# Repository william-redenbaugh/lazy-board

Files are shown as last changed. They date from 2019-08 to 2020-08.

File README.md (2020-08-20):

# Teensy Based Macro Board with RGB LEDs and a TFT LCD Display

Picture of prototype one

## Build of Materials:(Work in progress) 
- Teensy 4.0
- SSD1351 128x128 1.5in OLED display
- WS2813 RGB LEDs
- Keycaps TBD
- Keyswitches TBD
- PCB TBD

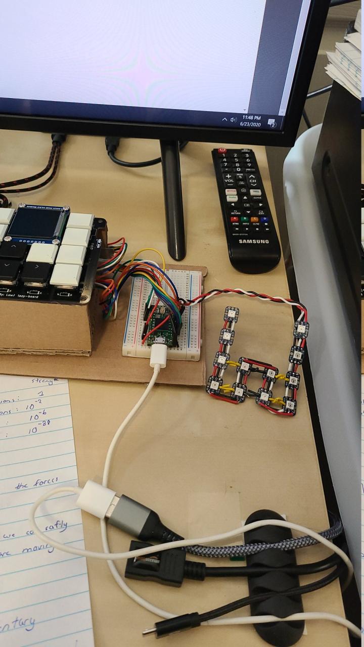
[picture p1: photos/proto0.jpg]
Picture of prototype zero


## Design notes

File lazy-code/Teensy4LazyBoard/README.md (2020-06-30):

# Teensy 4 Lazy Code
The firmware level code that will run on the lazy board. Will support RGB LED matrix, and a SPI based LCD. 

## Features: 
##### SPI DMA Based LCD Display control for pushing up gifs and images. 
##### PWM DMA Based LED Matrix for controlling the RGB LED Animations
##### Utilizes ChibiOS for multithreading purposes. 
##### Macro Configuration support through a header file
##### Interfaces with desktop app

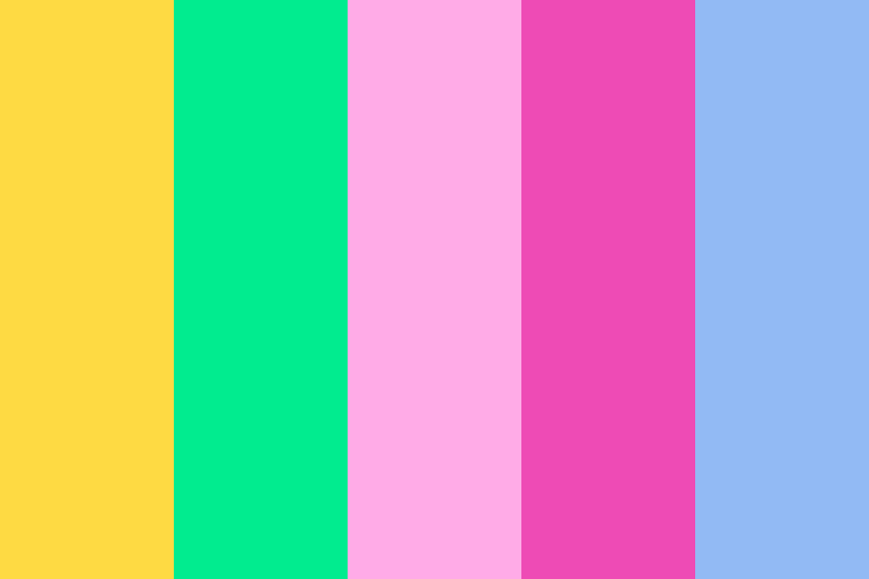
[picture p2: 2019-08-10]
Housing files/Housing working/easy_mode/pallette1.png

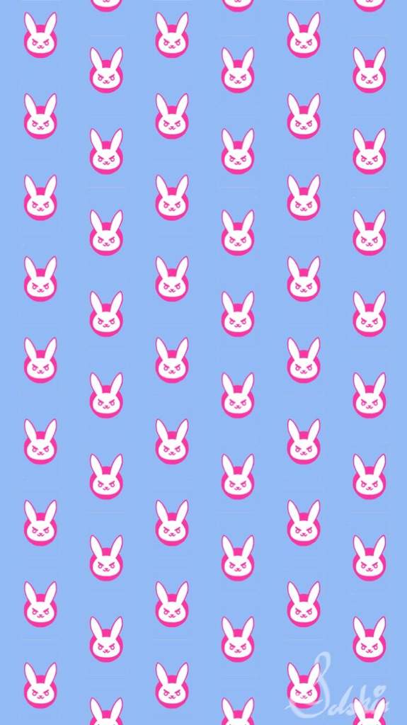
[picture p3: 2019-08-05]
Housing files/Housing working/easy_mode/1854acad1ce5d433ceb1f47706ed17edfe769c83_hq.jpg

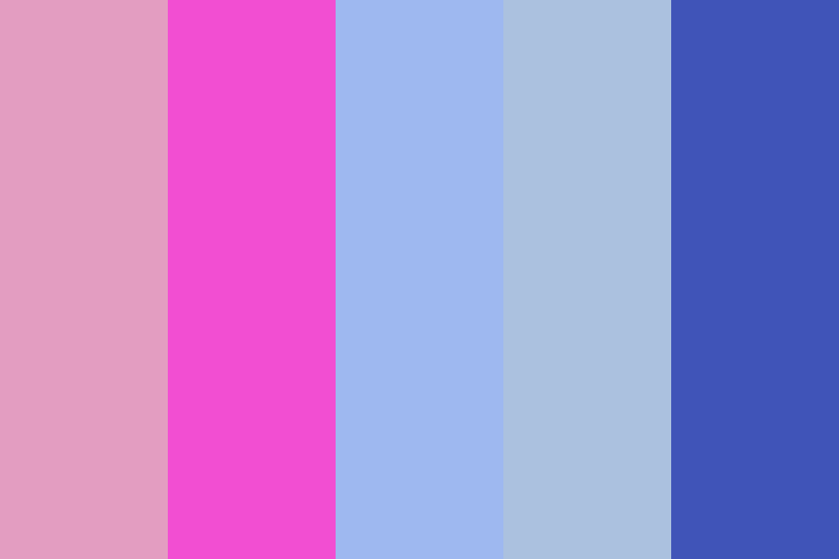
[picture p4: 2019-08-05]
Housing files/Housing working/easy_mode/pallette2.png

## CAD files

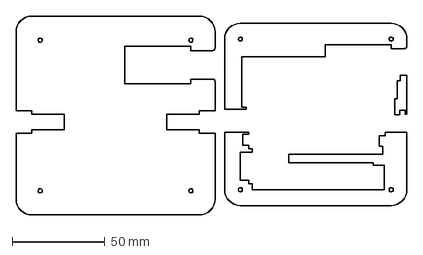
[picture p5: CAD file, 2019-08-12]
Housing files/Housing working/easy_mode/Pink/PinkLayer.dxf
210.8 x 107.3 mm

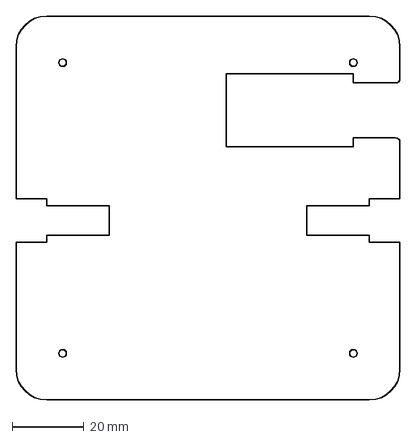
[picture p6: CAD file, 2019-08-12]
Housing files/Housing working/Layer 5/Layer5.dxf
107.3 x 107.3 mm

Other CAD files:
base.dxf
Housing files/Housing untested/DWG files(Solidworks export)/Layer3.DWG
Housing files/Housing untested/DXF(2000) files/Layer2.dxf
Housing files/Housing untested/Layer 1/Layer1.dxf
Housing files/Housing untested/Layer 2/Layer2.dxf
Housing files/Housing untested/Layer 3/Layer3.dxf
Housing files/Housing untested/Layer 4/Layer4v2.dxf
Housing files/Housing untested/Layer 5/Layer5.dxf
Housing files/Housing working/dxf 2000/Layer3.dxf
Housing files/Housing working/easy_mode/Lav/LavLayer.dxf
Housing files/Housing working/Layer 1 (bottom_cutout)/Layer1(cut_out).dxf
Housing files/Housing working/Layer 1/Layer1.dxf
Housing files/Housing working/Layer 2/Layer2.dxf
Housing files/Housing working/Layer 3/Layer3.dxf
Housing files/Housing working/Layer 4/Layer4v2.dxf
housing/Layer 4/Layer4.dxf
Housing files/Housing untested/DWG files(Solidworks export)/Layer1.DWG
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

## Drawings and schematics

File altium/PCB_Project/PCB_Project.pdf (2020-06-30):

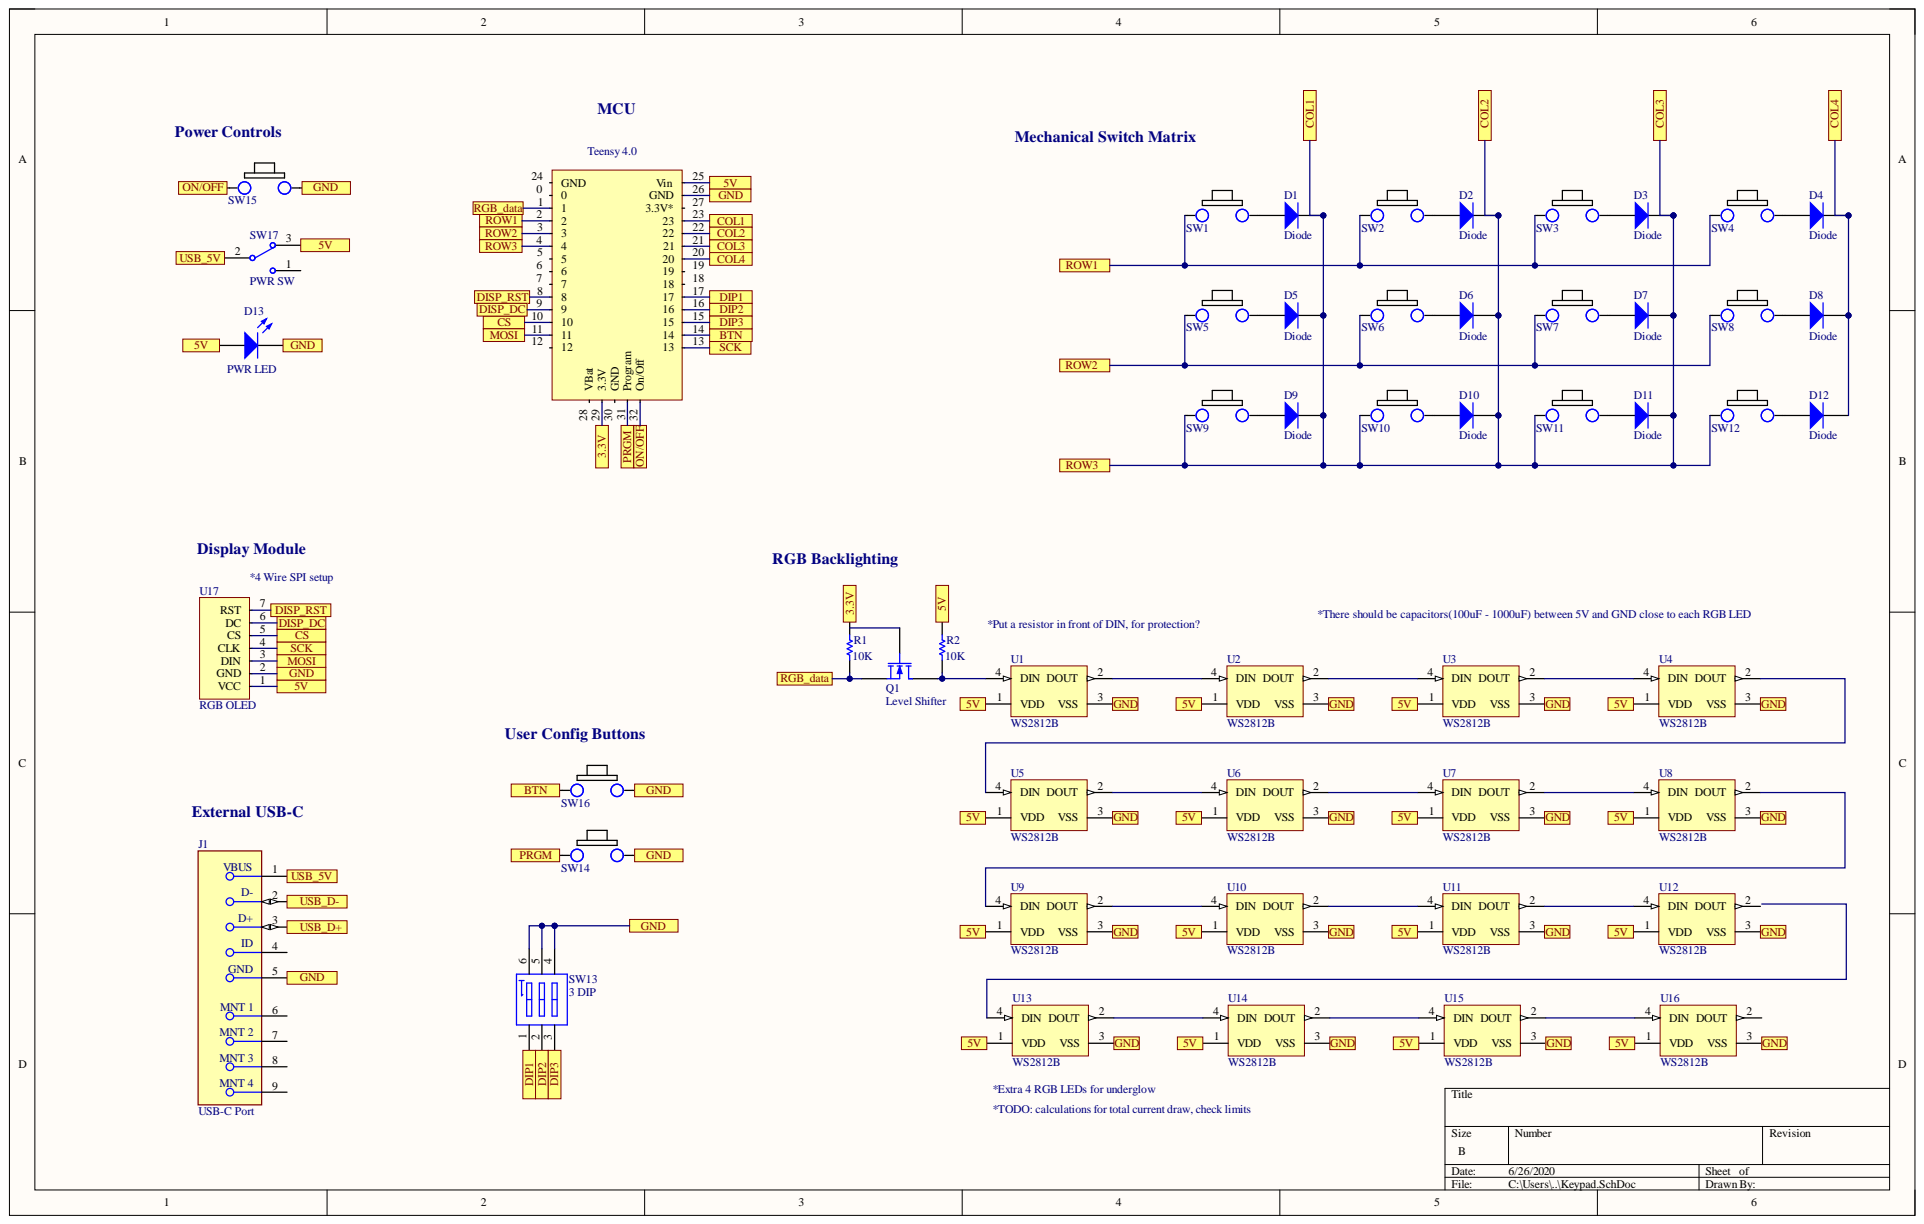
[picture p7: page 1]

RGB_data | 2 2
ROW1 | | COL1
ROW2 | | COL2

DISP_DC | 9 9 | DIP2

*Extra 4 RGB LEDs for underglow
*TODO: calculations for total current draw, check limits

Size B | Number | Revision

Date: 6/26/2020 | Sheet of
File: C:\Users\..\Keypad.SchDoc | DrawnBy:

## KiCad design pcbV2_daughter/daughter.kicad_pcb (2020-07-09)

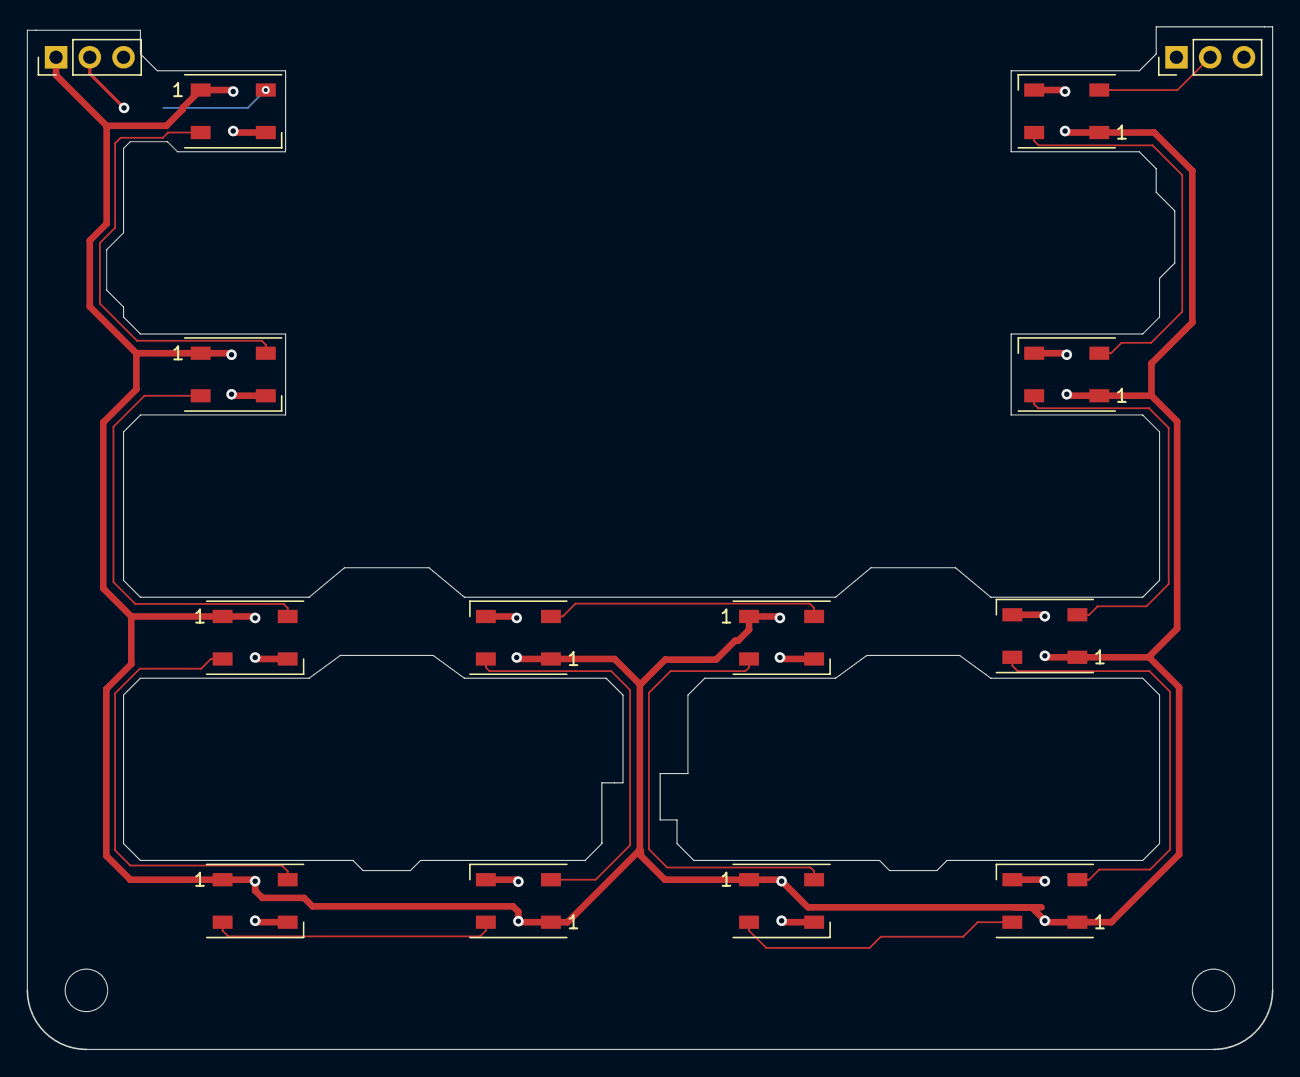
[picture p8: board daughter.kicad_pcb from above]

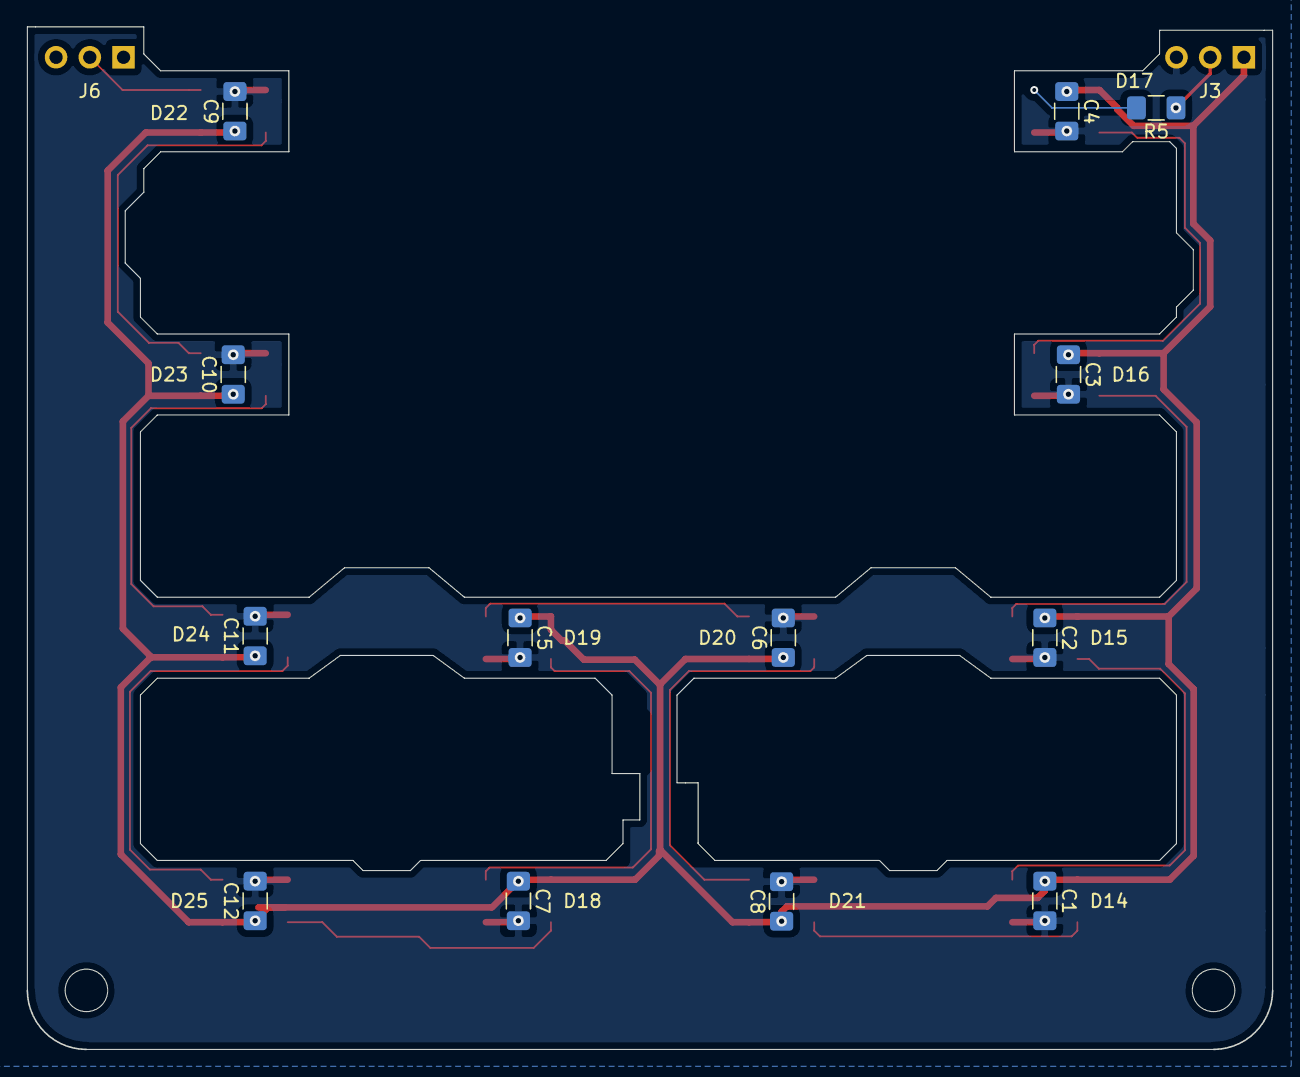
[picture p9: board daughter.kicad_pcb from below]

Board: 2 copper layers, 93.7 x 77.0 mm, 27 parts (13 on the bottom side), 16 nets.

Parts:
C1, C2, C3, C4, C5, C6, C7, C8, C9, C10, C11, C12: 1000uF; C_1206_3216Metric_Pad1.42x1.75mm_HandSolder
D14, D15, D16, D17, D18, D19, D20, D21, D22, D23, D24, D25: WS2812B; LED_WS2812B_PLCC4_5.0x5.0mm_P3.2mm
J3, J6: Conn_01x03_Male; PinHeader_1x03_P2.54mm_Vertical
R5: R_DIN; R_1206_3216Metric_Pad1.42x1.75mm_HandSolder

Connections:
+5V: C1.1, C2.1, C3.1, C4.1, C5.1, C6.1, C7.1, C8.1, C9.1, C10.1, C11.1, C12.1, D14.1, D15.1, D16.1, D17.1, D18.1, D19.1, D20.1, D21.1, D22.1, D23.1, D24.1, D25.1, J3.1
GND: C1.2, C2.2, C3.2, C4.2, C5.2, C6.2, C7.2, C8.2, C9.2, C10.2, C11.2, C12.2, D14.3, D15.3, D16.3, D17.3, D18.3, D19.3, D20.3, D21.3, D22.3, D23.3, D24.3, D25.3, J3.3
unnamed: D14.2, D21.4
unnamed: D14.4, D15.2
unnamed: D15.4, D16.2
unnamed: D16.4, D17.2
unnamed: D17.4, R5.1
unnamed: D18.2, D25.4
unnamed: D18.4, D19.2
unnamed: D19.4, D20.2
unnamed: D20.4, D21.2
unnamed: D22.4, D23.2
unnamed: D23.4, D24.2
unnamed: D24.4, D25.2
RGB_DIN: J3.2, R5.2
RGB_DOUT: D22.2, J6.2

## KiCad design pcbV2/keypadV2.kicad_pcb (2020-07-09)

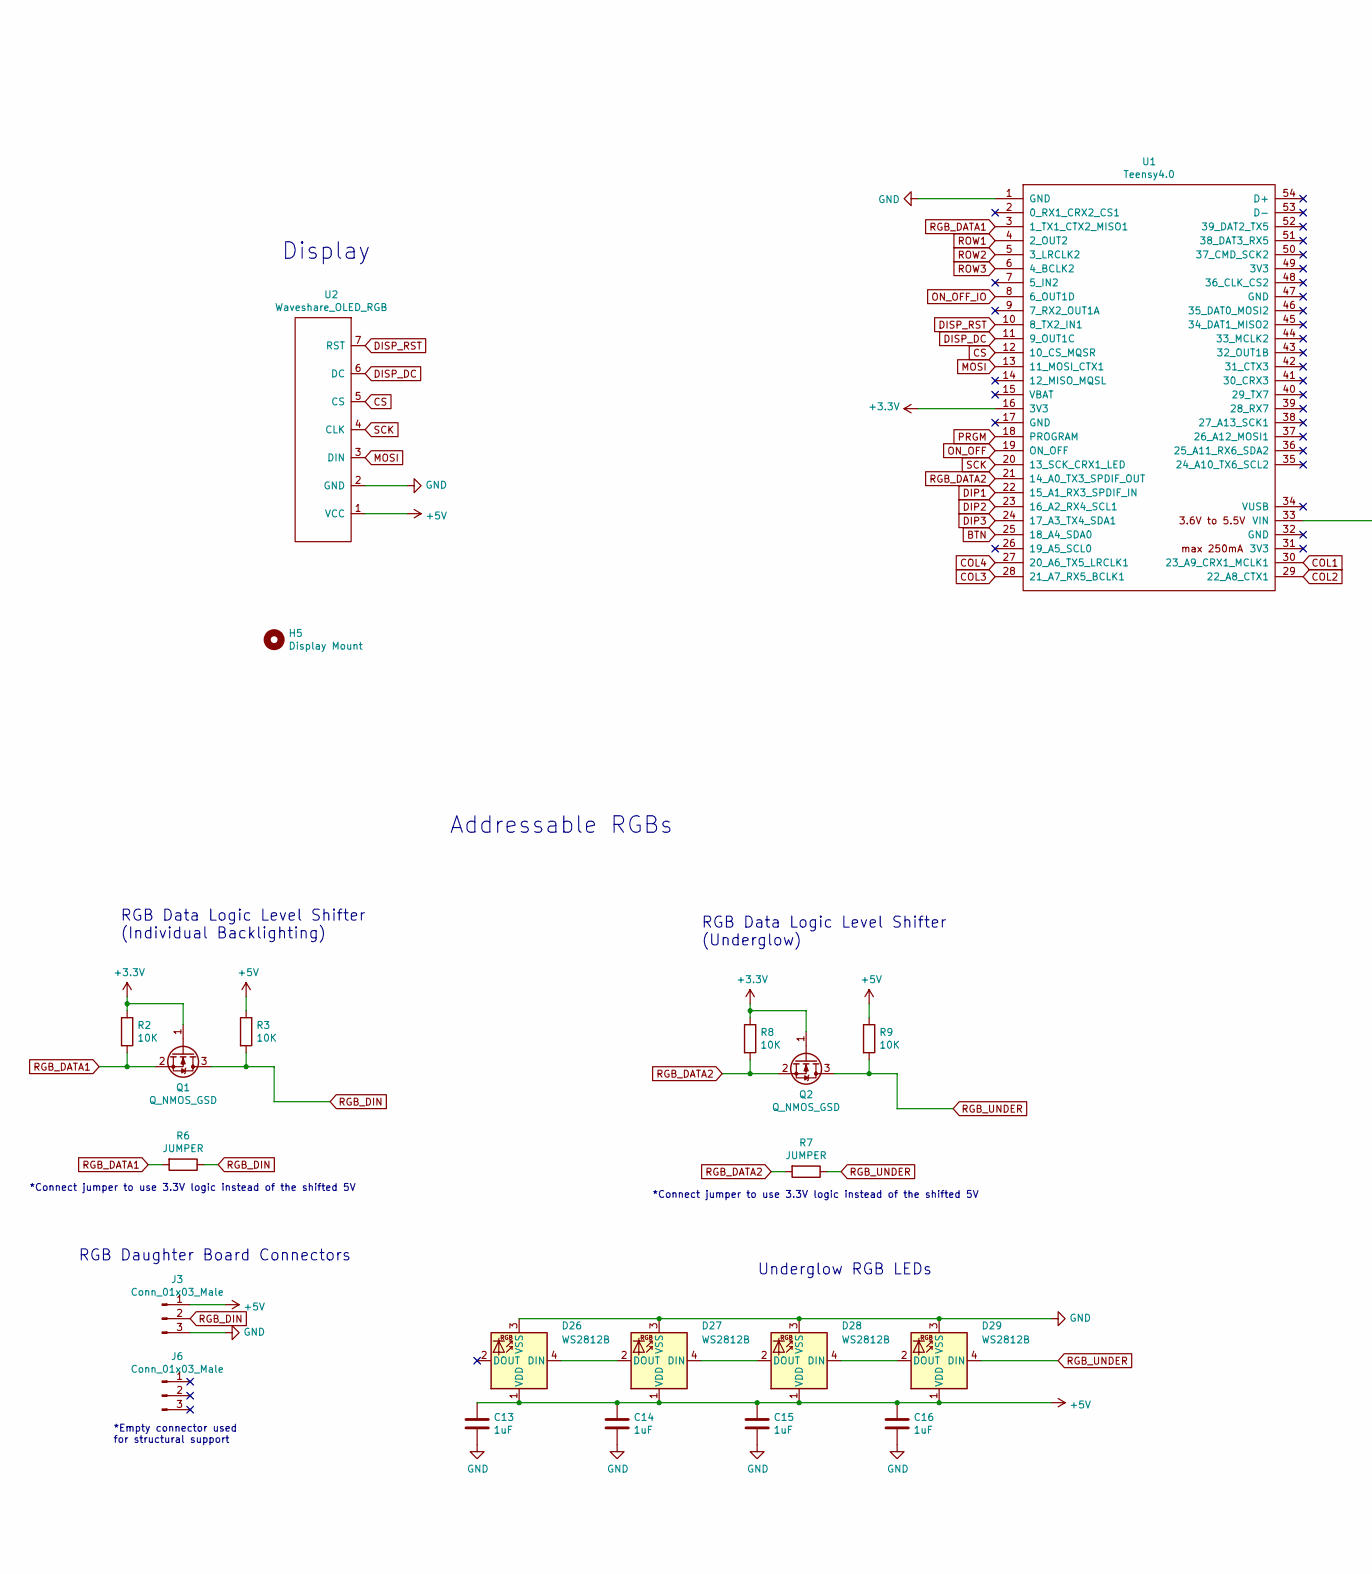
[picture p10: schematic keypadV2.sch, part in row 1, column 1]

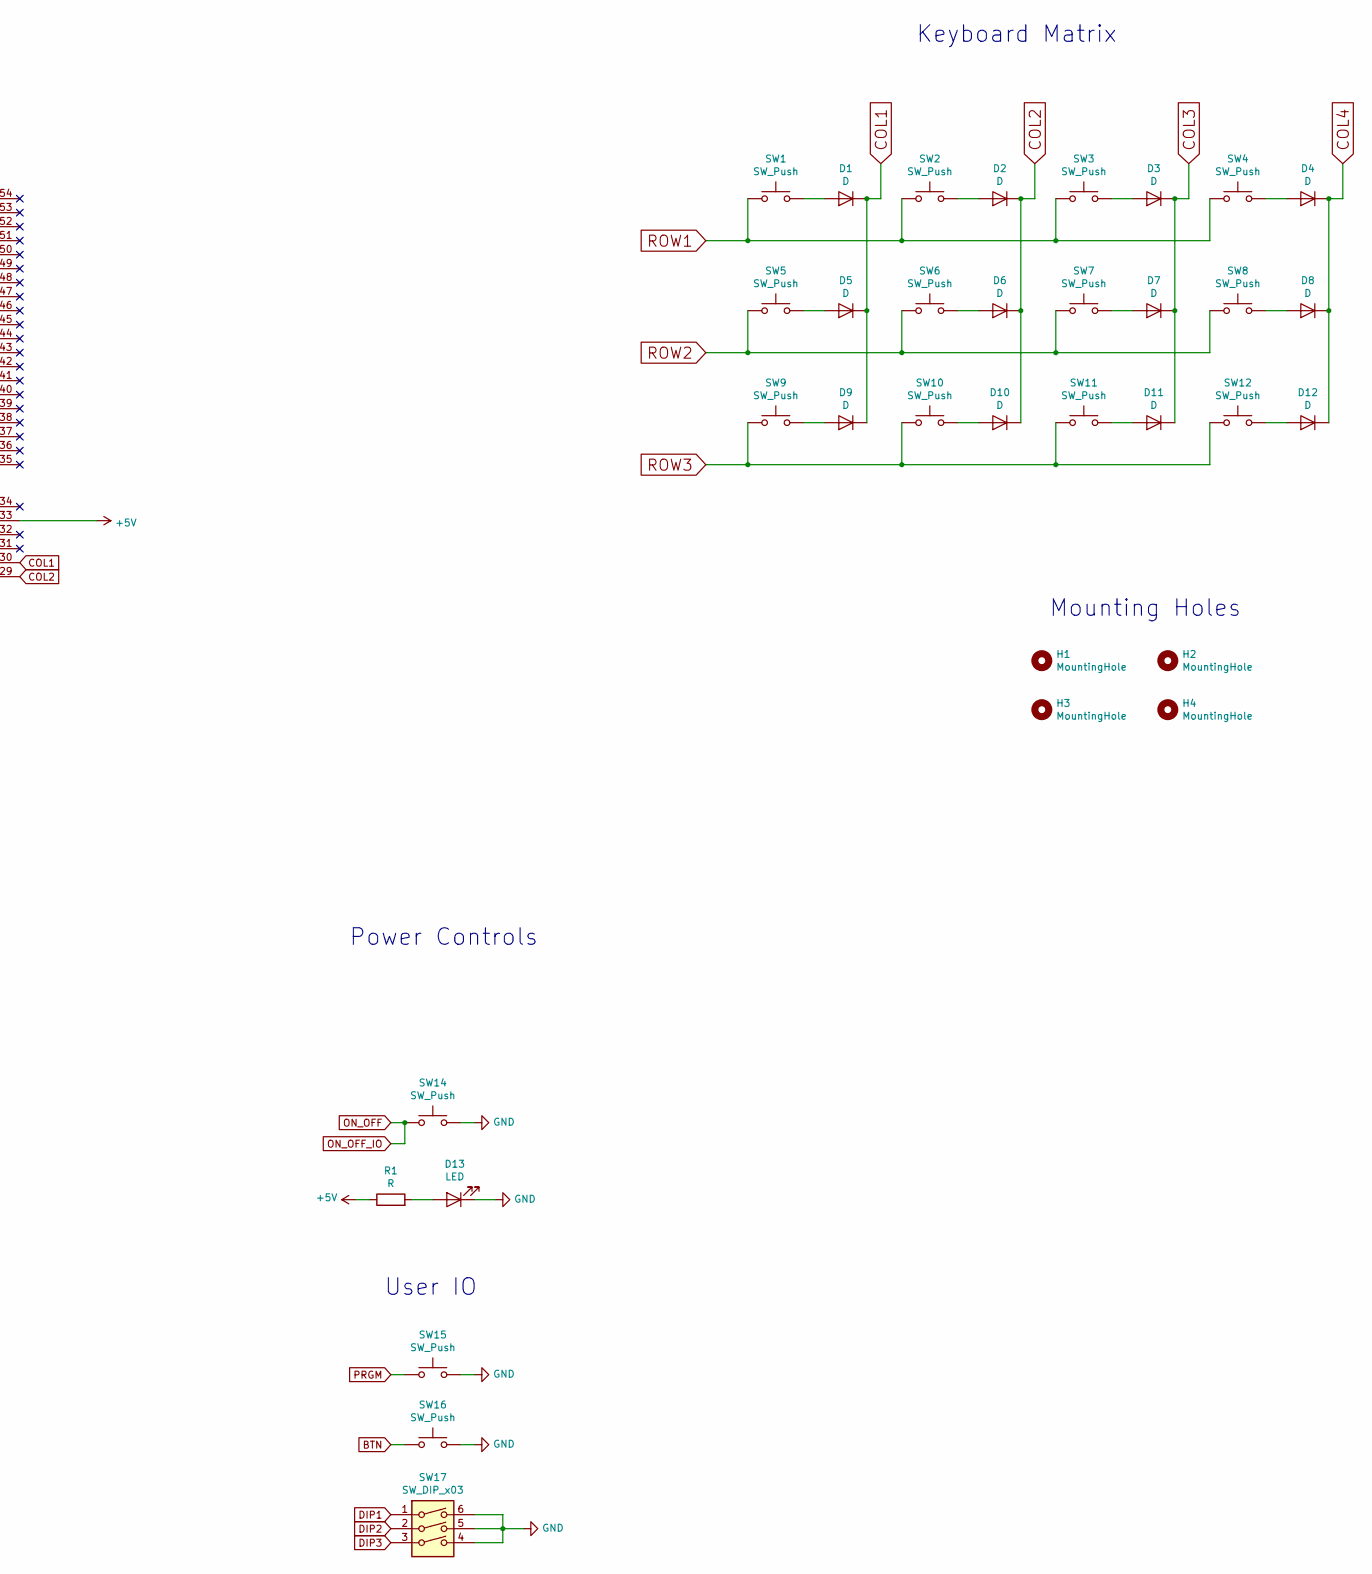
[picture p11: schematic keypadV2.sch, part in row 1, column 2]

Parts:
C13, C14, C15, C16: 1uF; C_1206_3216Metric_Pad1.42x1.75mm_HandSolder
D1, D2, D3, D4, D5, D6, D7, D8, D9, D10, D11, D12: D; D_SOD-323_HandSoldering
D13: LED; LED_1206_3216Metric_Pad1.42x1.75mm_HandSolder
D26, D27, D28, D29: WS2812B; LED_WS2812B_PLCC4_5.0x5.0mm_P3.2mm
H1, H2, H3, H4: MountingHole; MountingHole_3.2mm_M3
H5: Display Mount; Waveshare_LCD_mount V2
J3: Conn_01x03_Male; PinHeader_1x03_P2.54mm_Vertical
J6: Conn_01x03_Male; PinSocket_1x03_P2.54mm_Vertical
Q1, Q2: Q_NMOS_GSD; SOT-23
R1: R; R_1206_3216Metric_Pad1.42x1.75mm_HandSolder
R2, R3, R8, R9: 10K; R_1206_3216Metric_Pad1.42x1.75mm_HandSolder
R6, R7: JUMPER; R_1206_3216Metric_Pad1.42x1.75mm_HandSolder
SW1, SW2, SW3, SW4, SW5, SW6, SW7, SW8, SW9, SW10, SW11, SW12: SW_Push; Kailh_socket_MX
SW14, SW15, SW16: SW_Push; BTN_B3S-1000P
SW17: SW_DIP_x03; DIP3_219-3MSTR
U1: Teensy4.0; Teensy40_REDUCED_PINS
U2: Waveshare_OLED_RGB; PinHeader_1x07_P2.54mm_Vertical

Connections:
+3V3: Q1.1 (G), Q2.1 (G), R2.1, R8.1, U1.16 (3V3)
+5V: C13.1, C14.1, C15.1, C16.1, D26.1 (VDD), D27.1 (VDD), D28.1 (VDD), D29.1 (VDD), J3.1, R1.1, R3.1, R9.1, U1.33 (VIN), U2.1 (VCC)
BTN: SW16.1, U1.25 (18_A4_SDA0)
COL1: D1.1 (K), D5.1 (K), D9.1 (K), U1.30 (23_A9_CRX1_MCLK1)
COL2: D2.1 (K), D6.1 (K), D10.1 (K), U1.29 (22_A8_CTX1)
COL3: D3.1 (K), D7.1 (K), D11.1 (K), U1.28 (21_A7_RX5_BCLK1)
COL4: D4.1 (K), D8.1 (K), D12.1 (K), U1.27 (20_A6_TX5_LRCLK1)
CS: U1.12 (10_CS_MQSR), U2.5 (CS)
DIP1: SW17.1, U1.22 (15_A1_RX3_SPDIF_IN)
DIP2: SW17.2, U1.23 (16_A2_RX4_SCL1)
DIP3: SW17.3, U1.24 (17_A3_TX4_SDA1)
DISP_DC: U1.11 (9_OUT1C), U2.6 (DC)
DISP_RST: U1.10 (8_TX2_IN1), U2.7 (RST)
GND: C13.2, C14.2, C15.2, C16.2, D13.1 (K), D26.3 (VSS), D27.3 (VSS), D28.3 (VSS), D29.3 (VSS), J3.3, SW14.2, SW15.2, SW16.2, SW17.4, SW17.5, SW17.6, U1.1 (GND), U2.2 (GND)
MOSI: U1.13 (11_MOSI_CTX1), U2.3 (DIN)
unnamed: D1.2 (A), SW1.2
unnamed: D2.2 (A), SW2.2
unnamed: D3.2 (A), SW3.2
unnamed: D4.2 (A), SW4.2
unnamed: D5.2 (A), SW5.2
unnamed: D6.2 (A), SW6.2
unnamed: D7.2 (A), SW7.2
unnamed: D8.2 (A), SW8.2
unnamed: D9.2 (A), SW9.2
unnamed: D10.2 (A), SW10.2
unnamed: D11.2 (A), SW11.2
unnamed: D12.2 (A), SW12.2
unnamed: D13.2 (A), R1.2
unnamed: D26.4 (DIN), D27.2 (DOUT)
unnamed: D27.4 (DIN), D28.2 (DOUT)
unnamed: D28.4 (DIN), D29.2 (DOUT)
ON_OFF: SW14.1, U1.8 (6_OUT1D), U1.19 (ON_OFF)
PRGM: SW15.1, U1.18 (PROGRAM)
RGB_DATA1: Q1.2 (S), R2.2, R6.2, U1.3 (1_TX1_CTX2_MISO1)
RGB_DATA2: Q2.2 (S), R7.2, R8.2, U1.21 (14_A0_TX3_SPDIF_OUT)
RGB_DIN: J3.2, Q1.3 (D), R3.2, R6.1
RGB_UNDER: D29.4 (DIN), Q2.3 (D), R7.1, R9.2
ROW1: SW1.1, SW2.1, SW3.1, SW4.1, U1.4 (2_OUT2)
ROW2: SW5.1, SW6.1, SW7.1, SW8.1, U1.5 (3_LRCLK2)
ROW3: SW9.1, SW10.1, SW11.1, SW12.1, U1.6 (4_BCLK2)
SCK: U1.20 (13_SCK_CRX1_LED), U2.4 (CLK)

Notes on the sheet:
User IO
Power Controls
Display
Addressable RGBs
RGB Data Logic Level Shifter (Individual Backlighting)
*Connect jumper to use 3.3V logic instead of the shifted 5V
RGB Daughter Board Connectors
Keyboard Matrix
Underglow RGB LEDs
RGB Data Logic Level Shifter (Underglow)
*Empty connector used for structural support
Mounting Holes

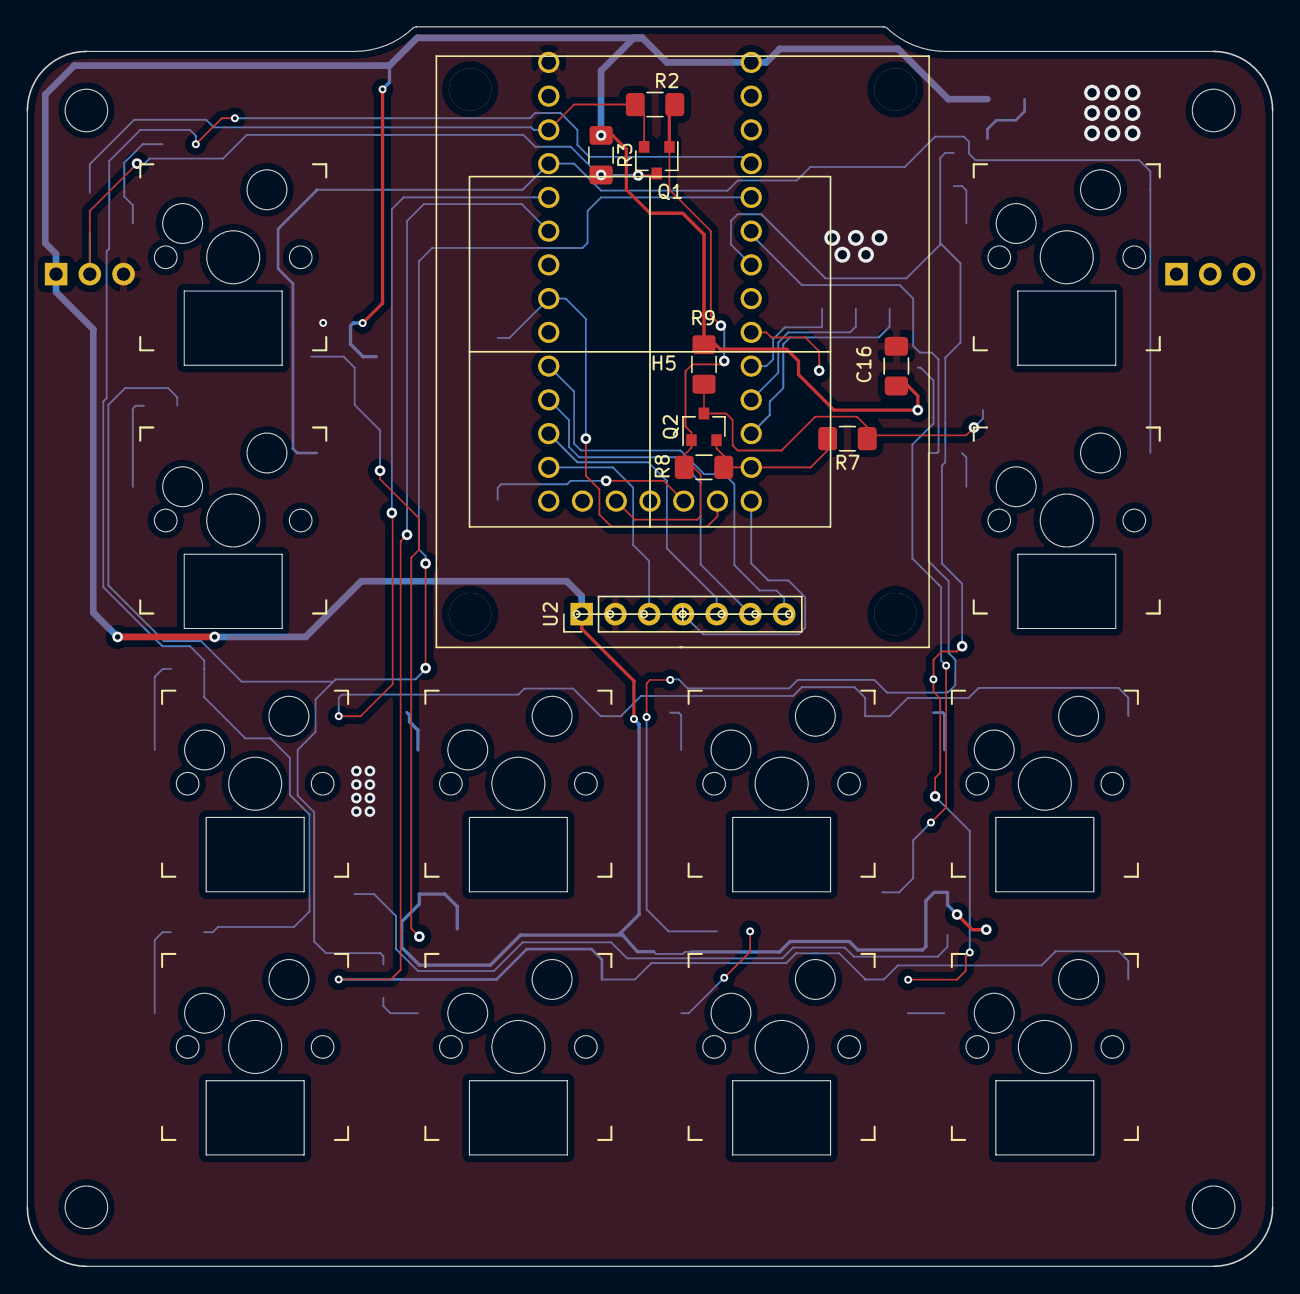
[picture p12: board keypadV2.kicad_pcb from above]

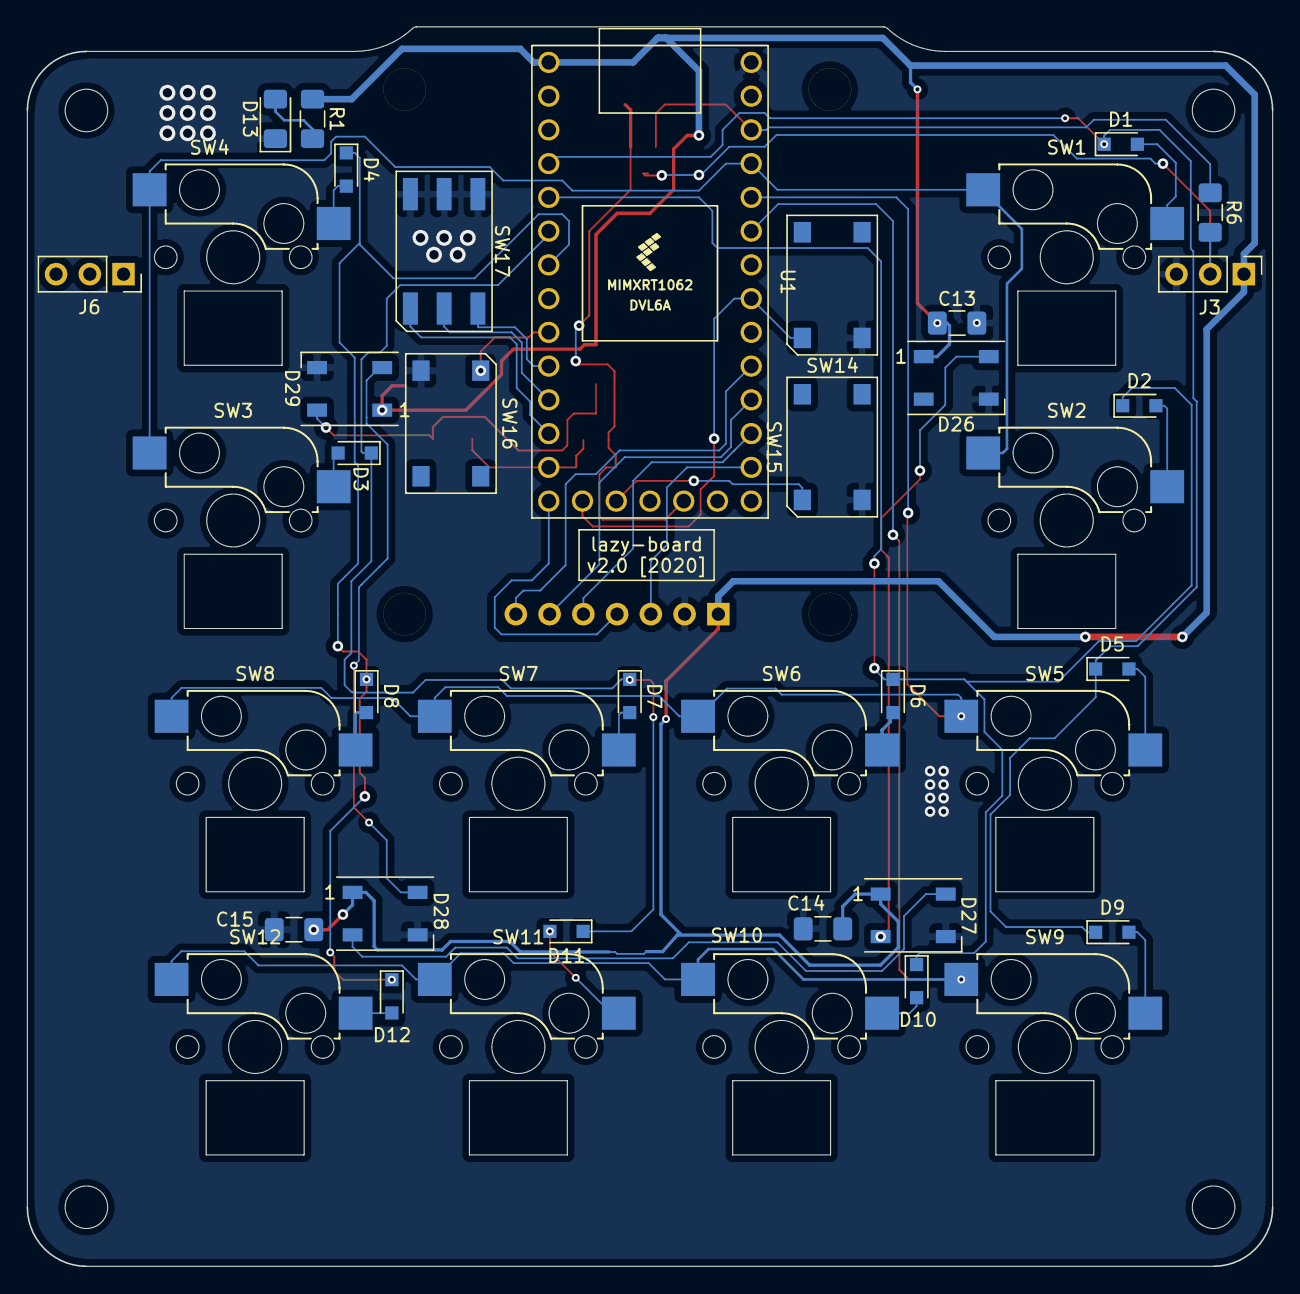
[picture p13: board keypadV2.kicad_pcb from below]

Board: 2 copper layers, 93.7 x 93.3 mm, 55 parts (28 on the bottom side), 41 nets.

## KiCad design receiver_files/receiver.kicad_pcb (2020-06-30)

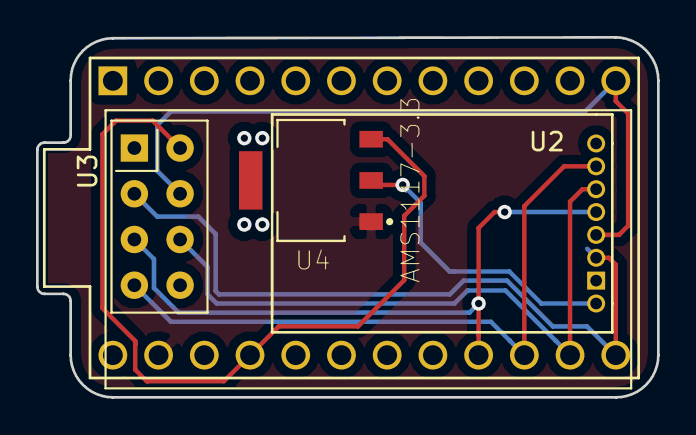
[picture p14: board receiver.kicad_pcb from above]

Board: 2 copper layers, 34.5 x 20.0 mm, 4 parts (1 on the bottom side), 8 nets.

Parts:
U1: ProMicro
U2: NRF24L01_Breakout; NR24l01mini
U3: NRF24L01_Breakout; nRF24L01_Breakout
U4: AMS1117-3.3; SOT229P700X180-4N

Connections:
/3.3V: U2.2, U4.2
/GND1: U1.23, U2.1, U3.1, U4.1
/VCC1: U1.21, U3.2, U4.3
unnamed: U1.12, U2.4, U3.4
unnamed: U1.13, U2.3, U3.3
unnamed: U1.14, U2.6, U3.6
unnamed: U1.15, U2.7, U3.7
unnamed: U1.16, U2.5, U3.5

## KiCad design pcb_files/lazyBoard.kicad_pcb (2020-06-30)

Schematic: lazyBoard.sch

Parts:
BT1: Battery_Cell; PinHeader_1x02_P2.54mm_Vertical
D1, D2, D3, D4, D5, D6, D7, D8, D9, D10, D11, D12, D13, D14, D15, D16: D; D_SOD123_axial_noSMD
D20, D21, D22, D23, D24, D25, D26, D27, D28, D29, D30, D31, D32, D33, D34, D35: LED; C_3528v1
J1, J2: AudioJack3_Ground; CUI_SJ-43514-SMT
K1, K2, K3, K4, K5, K6, K7, K8, K9, K10, K11, K12, K13, K14, K15, K16: KEYSW; PG1350_socket
R1, R2, R3: R; D_SOD123_axial
U1: ProMicro; ProMicroPinsFlipped
U2: NRF24L01_Breakout; nrf24l01header
U3, U5, U6: ADG417BN; PinHeader_1x03_P2.54mm_Vertical
U4: AMS1117-3.3; SOT229P700X180-4N
U7: TLC5940PWP; HTSSOP-28-1EP_4.4x9.7mm_P0.65mm_EP3.4x9.5mm_Mask2.4x6.17mm_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

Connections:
/Col1: K1.1, K5.1, K9.1, K13.1, U1.7 (D4)
/Col2: K2.1, K6.1, K10.1, K14.1, U1.1 (TX)
/Col3: K3.1, K7.1, K11.1, K15.1, U1.9 (D7)
/Col4: K4.1, K8.1, K12.1, K16.1, U1.20 (F4)
/GND1: BT1.2 (-), J1.4, J2.4, R3.1, U1.23 (GND), U2.1 (GND), U4.1, U7.1, U7.6
/GSCLK: U1.8 (C6), U7.25
/RAW1: J2.3, U1.24 (RAW), U3.2 (NC)
/Row1: D1.1 (K), D2.1 (K), D3.1 (K), D4.1 (K), U1.10 (E6)
/Row2: D5.1 (K), D6.1 (K), D7.1 (K), D8.1 (K), U1.11 (B4)
/Row3: D9.1 (K), D10.1 (K), D11.1 (K), D12.1 (K), U1.2 (RX)
/Row4: D13.1 (K), D14.1 (K), D15.1 (K), D16.1 (K), U1.19 (F5)
/VCC1: D20.1, D21.1, D22.1, D23.1, D24.1, D25.1, D26.1, D27.1, D28.1, D29.1, D30.1, D31.1, D32.1, D33.1, D34.1, D35.1, J1.3, U1.21 (VCC), U5.1, U6.2 (NC), U7.26, U7.28
unnamed: BT1.1 (+), U3.3 (GND)
unnamed: D1.2 (A), K1.2
unnamed: D2.2 (A), K2.2
unnamed: D3.2 (A), K3.2
unnamed: D4.2 (A), K4.2
unnamed: D5.2 (A), K5.2
unnamed: D6.2 (A), K6.2
unnamed: D7.2 (A), K7.2
unnamed: D8.2 (A), K8.2
unnamed: D9.2 (A), K9.2
unnamed: D10.2 (A), K10.2
unnamed: D11.2 (A), K11.2
unnamed: D12.2 (A), K12.2
unnamed: D13.2 (A), K13.2
unnamed: D14.2 (A), K14.2
unnamed: D15.2 (A), K15.2
unnamed: D16.2 (A), K16.2
unnamed: D20.2, U7.22
unnamed: D21.2, U7.21
unnamed: D22.2, U7.20
unnamed: D23.2, U7.19
unnamed: D24.2, U7.18
unnamed: D25.2, U7.17
unnamed: D26.2, U7.16
unnamed: D27.2, U7.15
unnamed: D28.2, U7.14
unnamed: D29.2, U7.13
unnamed: D30.2, U7.12
unnamed: D31.2, U7.11
unnamed: D32.2, U7.10
unnamed: D33.2, U7.9
unnamed: D34.2, U7.8
unnamed: D35.2, U7.7
unnamed: J1.1, J2.1, R2.1, U1.5 (SCL)
unnamed: J1.2, J2.2, R1.1, U1.6 (SDA)
unnamed: R1.2, R2.2, U5.2 (NC)
unnamed: R3.2, U7.27
unnamed: U1.12 (B5), U7.3
unnamed: U1.13 (B6), U7.2
unnamed: U1.14 (B2), U2.6 (MOSI), U7.5
unnamed: U1.15 (B3), U2.7 (MISO)
unnamed: U1.16 (B1), U2.5 (SCK), U7.4
unnamed: U1.17 (F7), U2.4 (~CSN)
unnamed: U1.18 (F6), U2.3 (CE)
unnamed: U2.2 (VCC), U4.2
unnamed: U4.3, U6.3 (GND)

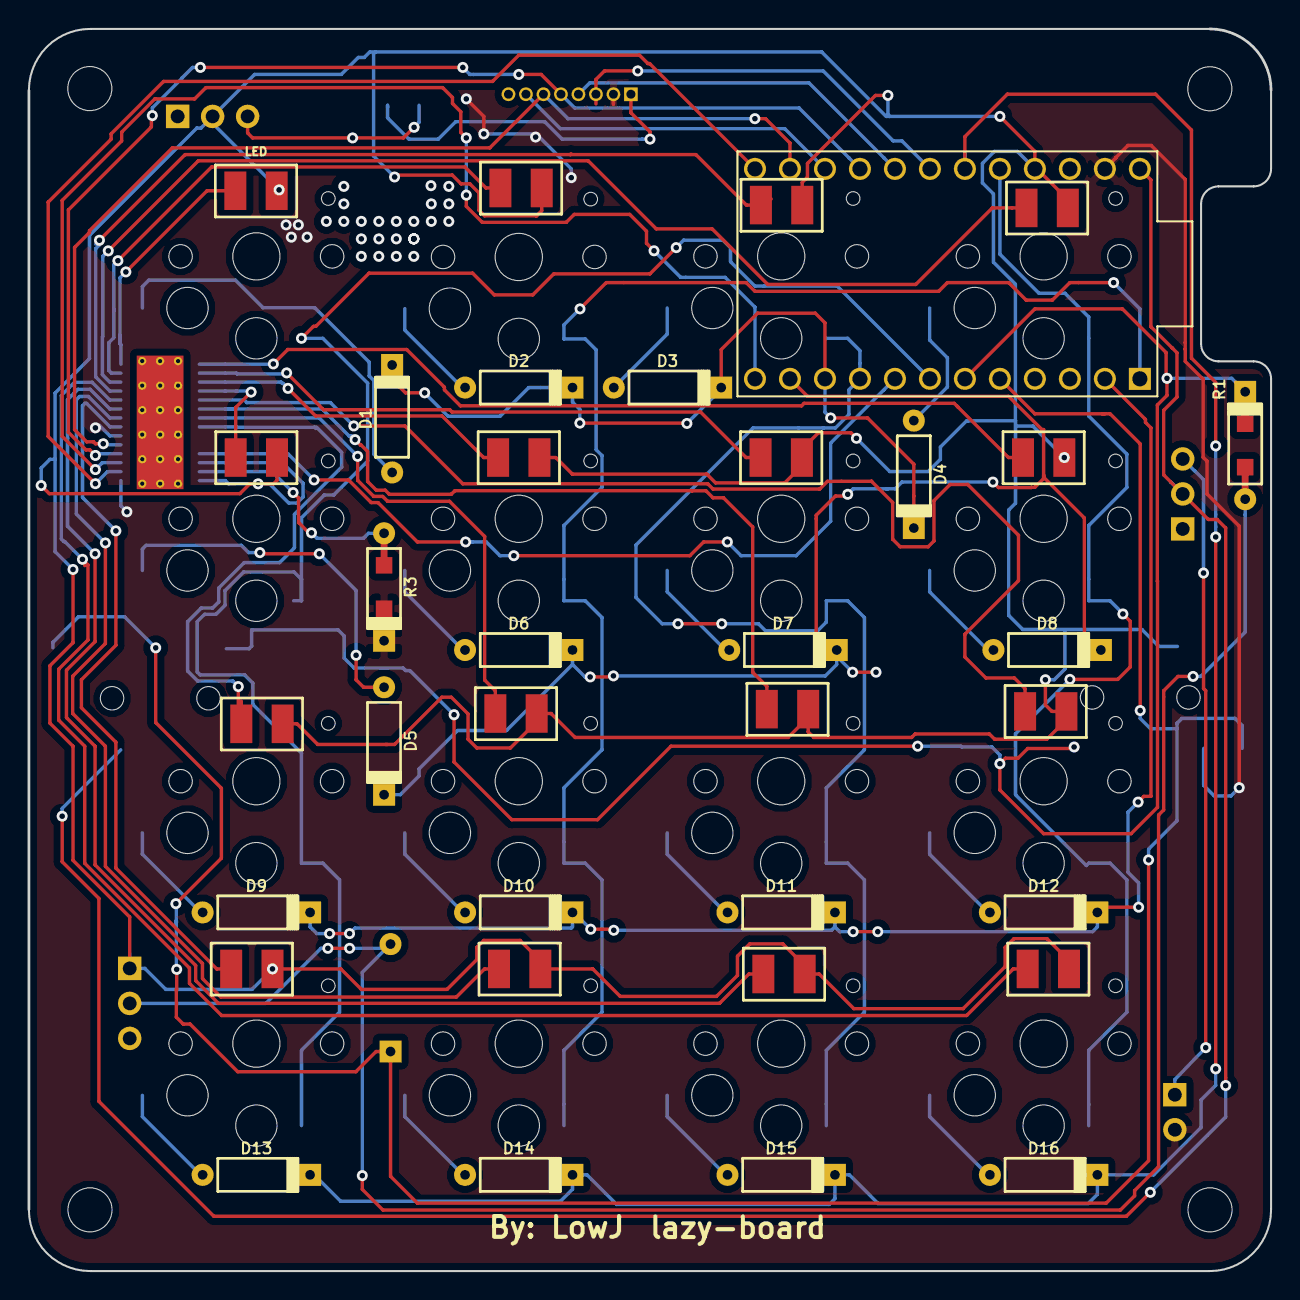
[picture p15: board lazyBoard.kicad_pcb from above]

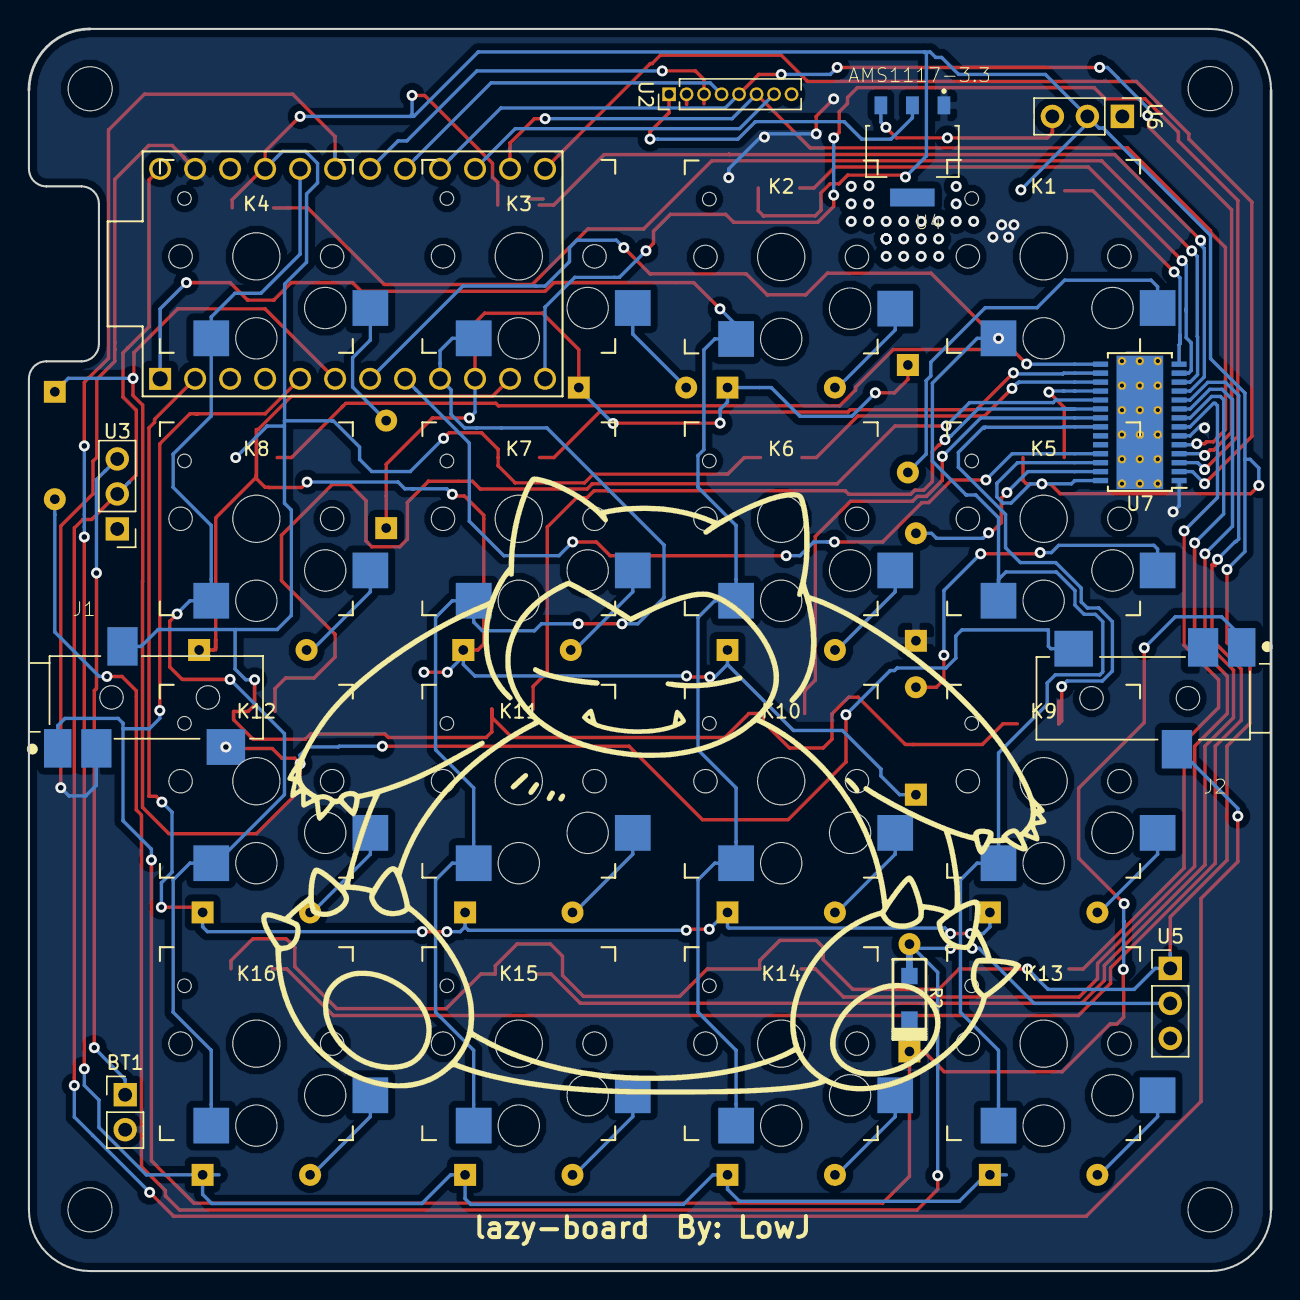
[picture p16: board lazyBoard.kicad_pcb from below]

Board: 2 copper layers, 90.2 x 90.2 mm, 61 parts (10 on the bottom side), 58 nets.

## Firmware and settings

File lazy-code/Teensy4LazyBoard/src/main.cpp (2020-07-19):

/*
Author: William Redenbaugh
Last Edit Date: 7/3/2020
*/

// Arduino and ChibiOS Libraries 
#include "Arduino.h"
#include "ChRt.h"

// Runtime files.
#include "keyboard_runtime_thread.hpp"
#include "keyboard_gpio.hpp"
#include "spi_display_runtime.hpp"
#include "led_matrix_runtime.hpp"
#include "message_management_thread.hpp"
#include "lwip_thread.hpp"
#include "button_gpio.hpp"

void setup_application_threads(void);
void setup_lp_threads(void);

/**************************************************************************/
/*!
    @brief Where we call our chibiOS initialization functions.
*/
/**************************************************************************/
void chibiSetup(void){
  // This is technically a runtime thread but it holds a bunch of subthreads to do work 
  //setup_lwip_thread();

  // Setting up message managment with the computer
  start_message_management();
  setup_application_threads();
  setup_lp_threads();
}

/**************************************************************************/
/*!
    @brief Where we call the initialization of our chibiOS application level threads. 
*/
/**************************************************************************/
void setup_application_threads(void){
  // Starting up our runtime threads
  start_keyboard_runtime_thread();
  start_led_strip_thread();
  start_spi_display_thread();
}

/**************************************************************************/
/*!
    @brief Where we call the initialization of our low priority threads
*/
/**************************************************************************/
void setup_lp_threads(void){
  // Starting up our low priority work threads:
  setup_dip_button();
}

/**************************************************************************/
/*!
    @brief All of our setup happens in here 
*/
/**************************************************************************/
void setup() {
  // We do all of our setup in here. 
  chBegin(chibiSetup);  
}

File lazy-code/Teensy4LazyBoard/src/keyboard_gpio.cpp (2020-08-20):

/*
Author: William Redenbaugh
Last Edit Date: 7/3/2020
*/

#include "keyboard_gpio.hpp"

// Pinmap of all the gpio pins for reading the keyboard matrix, rows and columns
uint8_t matrix_col_gpio[] = {KB_MATRIX_PIN_0, 
                             KB_MATRIX_PIN_1, 
                             KB_MATRIX_PIN_2};

uint8_t matrix_row_gpio[] = {KB_MATRIX_PIN_3, 
                             KB_MATRIX_PIN_4, 
                             KB_MATRIX_PIN_5, 
                             KB_MATRIX_PIN_6};  

KeyState key_state;

extern void start_keyboard_gpio(void);
extern void read_keyboard_gpio(void);
extern void get_keyboard_values(KeyState key_state_ptr);

/**************************************************************************/
/*!
    @brief allows us to get a pointer reference to the latest keyboard values
*/
/**************************************************************************/
extern void get_keyboard_values(KeyState key_state_ptr){
    for(uint8_t row = 0; row < NUM_ROWS * NUM_COLS; row++){
        key_state_ptr[row] = key_state[row];
    }
}

/**************************************************************************/
/*!
    @brief allows us to read in the latest keyboard gpio values
*/
/**************************************************************************/
extern void read_keyboard_gpio(void){
    uint8_t x = 0;
    for(uint8_t row = 0; row < NUM_ROWS; row++){
        pinMode(matrix_row_gpio[row], OUTPUT);
        digitalWriteFast(matrix_row_gpio[row], LOW);
        
        for(uint8_t col = 0; col < NUM_COLS; col++){
            pinMode(matrix_col_gpio[col], INPUT_PULLUP);
            chThdSleepMilliseconds(1);
            key_state[x] = (uint8_t)digitalReadFast(matrix_col_gpio[col]);
            x++;
            pinMode(matrix_col_gpio[col], INPUT);
        }
        pinMode(matrix_row_gpio[row], INPUT);
    }
}

/**************************************************************************/
/*!
    @brief Allows us to setup our keyboard gpio
*/
/**************************************************************************/
extern void start_keyboard_gpio(void){
    // Clearing key state values
    for(uint8_t row = 0; row < NUM_ROWS * NUM_COLS; row++){
        key_state[row] = 1; 
    } 
}

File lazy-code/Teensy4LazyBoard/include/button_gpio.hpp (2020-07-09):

/*
Author: William Redenbaugh
Last Edit Date: 7/3/2020
*/

#ifndef _BUTTON_GPIO_HPP
#define _BUTTON_GPIO_HPP

#include "Arduino.h"
#include "ChRt.h"
#include "lwip_thread.hpp"

#define DIP1 17
#define DIP2 16
#define DIP3 15
#define BUTTON 14

extern void setup_dip_button(void);
#endif 

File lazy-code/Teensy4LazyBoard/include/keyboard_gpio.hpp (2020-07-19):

/*
Author: William Redenbaugh
Last Edit Date: 7/3/2020
*/

#ifndef _KEYBOARD_GPIO_HPP
#define _KEYBOARD_GPIO_HPP

// Arduino and ChibiOS Libraries 
#include "Arduino.h"
#include "ChRt.h"

// Keyboard matrix pins.

// Row pins
#define KB_MATRIX_PIN_0 2
#define KB_MATRIX_PIN_1 3
#define KB_MATRIX_PIN_2 4

// Column Pins
#define KB_MATRIX_PIN_3 23
#define KB_MATRIX_PIN_4 22
#define KB_MATRIX_PIN_5 21
#define KB_MATRIX_PIN_6 20

/**************************************************************************/
/*!
    @brief Size of our matrix array. 
*/
/**************************************************************************/
enum matrix_size_t {NUM_COLS = 3, 
                    NUM_ROWS = 4
                    };                      

/**************************************************************************/
/*!
    @brief The position of all of our keyboard macros
*/
/**************************************************************************/
enum kb_macro_pos_t{
    KB_MACRO_0_POS = 0,   
    KB_MACRO_1_POS = 1,   
    KB_MACRO_2_POS = 2,  
    KB_MACRO_3_POS = 3,   
    KB_MACRO_4_POS = 4,   
    KB_MACRO_5_POS = 5,   
    KB_MACRO_6_POS = 6,   
    KB_MACRO_7_POS = 7,   
    KB_MACRO_8_POS = 8,   
    KB_MACRO_9_POS = 9,   
    KB_MACRO_10_POS = 10,   
    KB_MACRO_11_POS = 11,   
    
    // Unused macros
    KB_MACRO_12_POS = 12,   
    KB_MACRO_13_POS = 13,   
    KB_MACRO_14_POS = 14,   
    KB_MACRO_15_POS = 15
};

/**************************************************************************/
/*!
    @brief redefined array that has our row and colum space. 
*/
/**************************************************************************/
typedef volatile uint8_t KeyState[NUM_ROWS * NUM_COLS]; 

extern void start_keyboard_gpio(void);
extern void read_keyboard_gpio(void);
extern void get_keyboard_values(KeyState key_state_ptr);


#endif

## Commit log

2019-02-11 added ground plane
    [_saved_arrowPad.sch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]
2019-02-11 added cu ground plane
    [arrowPad.kicad_pcb]
2019-02-13 added status led
    [_saved_arrowPad.sch, arrowPad.kicad_pcb]
2019-02-13 added drill holes
    [_saved_arrowPad.sch, arrowPad.kicad_pcb]
2019-02-13 added wired communication between boards
    [_saved_arrowPad.sch, arrowPad.kicad_pcb, arrowPad.sch]
2019-02-15 final v1
    [arrowPad-B.Cu.gbr, arrowPad-B.Mask.gbr, arrowPad-B.Paste.gbr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]
2019-03-21 added code
    [arrowPad.kicad_pcb, arrowPad.sch]
2019-03-24 started reworking board
    [_saved_arrowPad.sch, arrowPad.kicad_pcb]
2019-03-24 updated schem
    [_saved_arrowPad.sch, arrowPad.sch]
2019-04-04 switch and diode pcb layout
    [_saved_arrowPad.sch, arrowPad.kicad_pcb]
2019-04-04 layed out components
    [_saved_arrowPad.sch, arrowPad.kicad_pcb, arrowPad.sch]
2019-04-04 flipped the position of nrf24l01
    [arrowPad.kicad_pcb]
2019-04-08 start tracing
    [arrowPad.kicad_pcb, arrowPad.sch]
2019-04-12 added traces to key matrix
    [arrowPad.kicad_pcb]
2019-04-18 ldo heat sink and edge cuts
    [arrowPad.kicad_pcb]
2019-04-19 started led matrix
    [_saved_arrowPad.sch]
2019-04-25 TLC5940 LED controller
    [_saved_arrowPad.sch, arrowPad.kicad_pcb, arrowPad.sch]
2019-04-27 traces from led ic
    [_saved_arrowPad.sch, arrowPad.kicad_pcb, arrowPad.sch]
2019-04-27 matrix and nrf24l01 traces
    [arrowPad.kicad_pcb]
2019-04-28 finished traces
    [arrowPad.kicad_pcb]
2019-04-30 adding TLC5940 connections
    [_saved_arrowPad.sch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]
2019-05-01 reworked led wiring
    [_saved_arrowPad.sch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]
2019-05-01 cleaned up traces
    [arrowPad.kicad_pcb]
2019-05-02 cleaned up board text
    [_saved_arrowPad.sch, arrowPad.kicad_pcb, arrowPad.sch]
2019-05-02 cleand up traces
    [arrowPad-B.Cu.gbr, arrowPad-B.Mask.gbr, arrowPad-B.Paste.gbr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]
2019-05-02 add pcb for receiver
    [receiver.kicad_pcb, receiver.sch]
2019-05-17 pcb sent to print
    [arrowPad-B.Cu.gbr, arrowPad-B.Mask.gbr, arrowPad-B.Paste.gbr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]
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2019-05-24 Added housing files for laser cutting
    [Layer1.dxf, Layer2.dxf, Layer3.dxf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]
2019-05-28 housing CAD v1
    [Layer1.dxf, Layer2.dxf, Layer3.dwg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]
2019-05-28 dwg files for houisng
    [Layer1.SLDDRW, Layer2.SLDDRW, Layer3.SLDDRW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]
2019-05-28 added dwg files
    [Layer1.DWG, Layer2.DWG, Layer3.DWG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]
2019-05-29 added v2 of housing
    [Layer1.dxf, Layer2.dxf, Layer3.dwg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]
2019-06-05 reverted pcb_files
    [arrowPad-B.Cu.gbr, arrowPad-B.Mask.gbr, arrowPad-B.Paste.gbr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]
2019-06-22 added image for pcb
    [arrowPad.kicad_pcb, arrowPad.sch]
2019-06-23 snorlax in silk screen
    [Layer1.DWG, Layer1.SLDDRW, Layer1.dxf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]
2019-06-24 fixed unconnected grounds
    [arrowPad.kicad_pcb]
2019-06-25 re added mounting holes
    [arrowPad.kicad_pcb, arrowPad.sch, receiver.kicad_pcb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]
2019-06-25 renamed project
    [arrowPad-B.Cu.gbr, arrowPad-B.Mask.gbr, arrowPad-B.Paste.gbr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]
2019-08-05 updated housing
    [Layer5.dwg, Layer5.dxf]
2019-08-05 Layer5 better fit
    [Layer5.dwg, Layer5.dxf]
2019-08-10 modified casing, #2 holes
    [Layer1(cut_out).dxf, Layer1.dxf, Layer2.dxf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]
2019-08-10 updated housing layer 4
    [Layer4v2.dxf]
2019-08-12 updated casing
    [LavLayer.dxf, Layer2.dxf, Layer4v2.dxf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]
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2020-06-08 set pin denominations and created thread and stack space for all of our runtime threads
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2020-06-10 Revert "mm"
    This reverts commit 577ec9d6cdd566b4086e94dff4a681b290f74ba2.
    [keyboard_gpio.cpp, keyboard_gpio.hpp, main.cpp]
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2020-06-11 Binded LEDs to Macros and fixed led matrix function. Added HSV support.
    [led_matrix_handler.cpp, led_matrix_handler.hpp]
2020-06-12 made some changes, fixed grammar, enabled display thread
    [keyboard_gpio.hpp, main.cpp]
2020-06-12 Some fixes and updates
    -Fixed typo in rgb -> hsv conversion for led matrix.
    [led_matrix_handler.cpp]
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2020-06-17 properly fixed ghosting issues with keyboard, changed the keyboard macros to the relevant ones, modified the LCD librariy, started working on the reactive animations for led runtime
    [keyboard_gpio.cpp]
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2020-06-22 moved stuff to prevent submodule errors, added documentation to new led library, added set rotation feature, fixed color bit length issues
    [spi_display_runtime.cpp]
2020-06-22 Started working on testing for board, implemented a bunch of fast math stuff, improved spi display runtime, fixed sleep mode, slight changes to macros
    [spi_display_runtime.cpp, spi_display_runtime.hpp]
2020-06-25 Started Altiumboard
    [Keypad.PcbDoc, Keypad.SchDoc, PCB_Project.PrjPcb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]
2020-06-25 Added basic IO, switches, buttons, USBC, to schem
    [Keypad.SchDoc, Schlib1.SchLib]
2020-06-26 Schematic v1
    [Keypad.SchDoc, Schlib1.SchLib]
2020-06-26 PDF added notes to schematic
    [Keypad.SchDoc]
2020-06-26 Added notes and LEDs for underglow
    [Keypad.SchDoc]
2020-06-26 updated project pdf
    [Keypad.SchDoc]
2020-06-26 save changes
    [PCB_Project.PrjPcb]
2020-06-26 started switch footprint, double check measurements
    [PcbLib1.PcbLib]
2020-06-26 rgb_data now on pin 1
    [Keypad.SchDoc, Schlib1.SchLib]
2020-06-26 added pcb stuff
    [Layer1.dxf, Layer2.dxf, Layer3.dxf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]
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2020-06-26 chaged file stucture
    [keypadV2.kicad_pcb, keypadV2.sch]
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2020-06-27 start pcb layout
    [keypadV2.kicad_pcb, keypadV2.sch]
2020-06-27 remade teensy footprint
    [keypadV2.kicad_pcb, keypadV2.sch]
2020-06-28 basic layout v1
    [keypadV2.kicad_pcb]
2020-06-28 created footprint for lcd
    [keypadV2.kicad_pcb]
2020-06-28 add update
    [keypadV2.sch]
2020-06-28 edge cuts
    [keypadV2.kicad_pcb]
2020-06-28 added ws2812b cutouts
    [keypadV2.kicad_pcb]
2020-06-28 started layout of daughterboard
    [keypadV2.kicad_pcb]
2020-06-28 component layout v1
    [keypadV2.kicad_pcb]
2020-06-28 Start daughterboard
    [daughter.kicad_pcb, daughter.sch, keypadV2.kicad_pcb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]
2020-06-29 finished v1 of daughter board
    [daughter.kicad_pcb, daughter.sch]
2020-06-29 Updated schematic on mainboard, LEDs moved to daughter board
    [keypadV2.kicad_pcb, keypadV2.sch]
2020-06-29 added mouting holes
    [keypadV2.kicad_pcb]
2020-06-29 Updated schematic to use seperate RGB Data pin for underglow LEDs
    [keypadV2.sch]
2020-06-29 Added components for 2nd RGB Data line
    [keypadV2.kicad_pcb]
2020-06-29 Started laying traces
    [keypadV2.kicad_pcb]
2020-06-30 3.3V was on wrong pin on teens
    [keypadV2.kicad_pcb, keypadV2.sch]
2020-06-30 finished tracing
    [keypadV2.kicad_pcb]
2020-06-30 updated pcb
    [keypadV2.kicad_pcb]
2020-06-30 updates for tonight
    [keypadV2.kicad_pcb]
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2020-07-09 Prototype 1 Code changes (#9)
    * started working on low priority work thread
    * removed usb c
    * setup a low priority worker thread that we can assign a bunch of menial tasks to
    * added dip switch support
    * started rewiring
    * v2 layout
    * edited layout, updated daughter board
    * moved some labels around
    * generated plots files
    * added the ability to enable, disable and delete threads by handler ID
    * added thread safety to the low priority work thread
    * added documentation for dip switches
    * finished adding thread safety code, fixed SPI dma ram waste usage
    * update
    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
    [daughter-B_Cu.gbr, daughter-B_Mask.gbr, daughter-B_Paste.gbr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]
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
